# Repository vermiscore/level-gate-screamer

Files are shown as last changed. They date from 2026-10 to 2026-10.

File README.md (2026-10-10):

# level-gate-screamer
Tube Screamer-style overdrive with a level gate: attenuates below threshold, boosts above

> [!WARNING]
> **v1: J2/J3 footprints are rotated 180°.**
> Fix with jumpers on the bottom side:
> - J2: 1–6, 2–5
> - J3: 1–6, 4–2
>
> Next revision: rotate J2/J3 so the big protrusion faces the board edge.
>
> **Output level:** up to ~9 Vpp (rail-to-rail op-amps on 9 V).
> Check the input range of the next device before connecting.
> Tested OK with a Neural DSP Nano Cortex.

## Files
- `kicad_files/` — KiCad project
- `fabrication/` — Gerber, BOM, CPL for JLCPCB
- `hand_soldered_parts/` — parts not assembled by JLCPCB
- `simulation/` — ngspice netlist

## Images

### Finished PCB
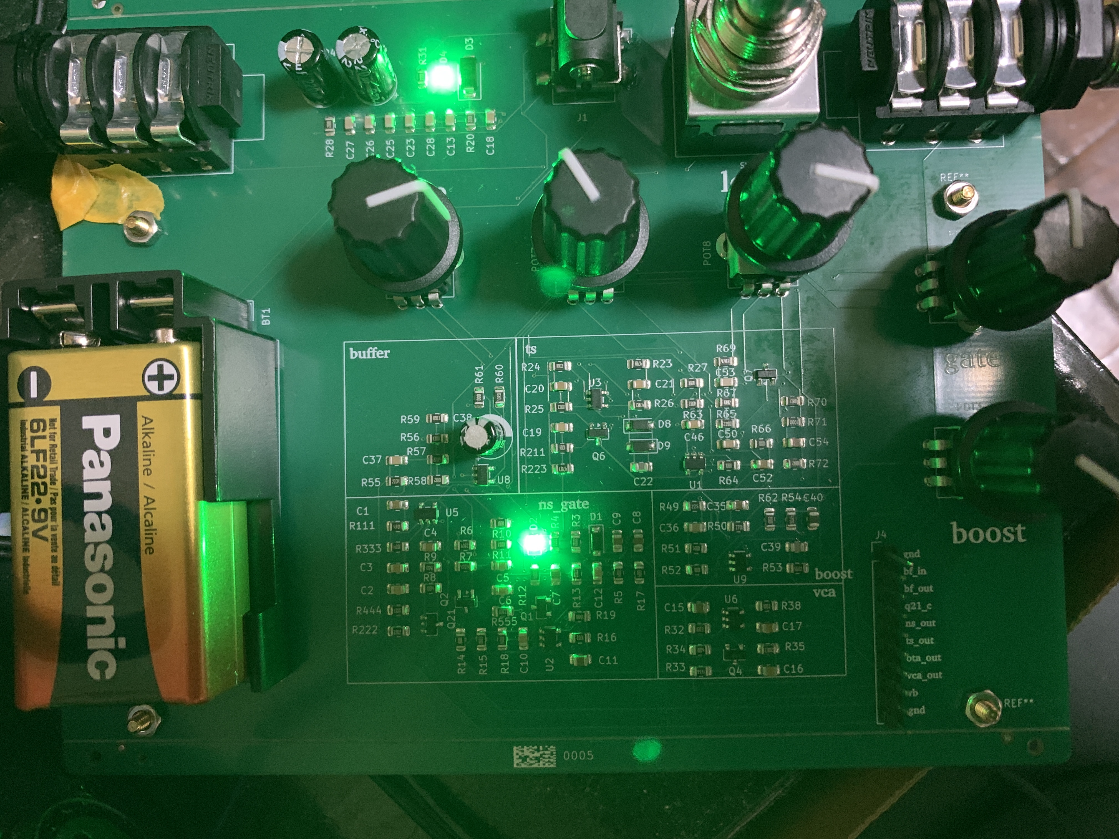
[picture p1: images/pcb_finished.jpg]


### PCB just arrived
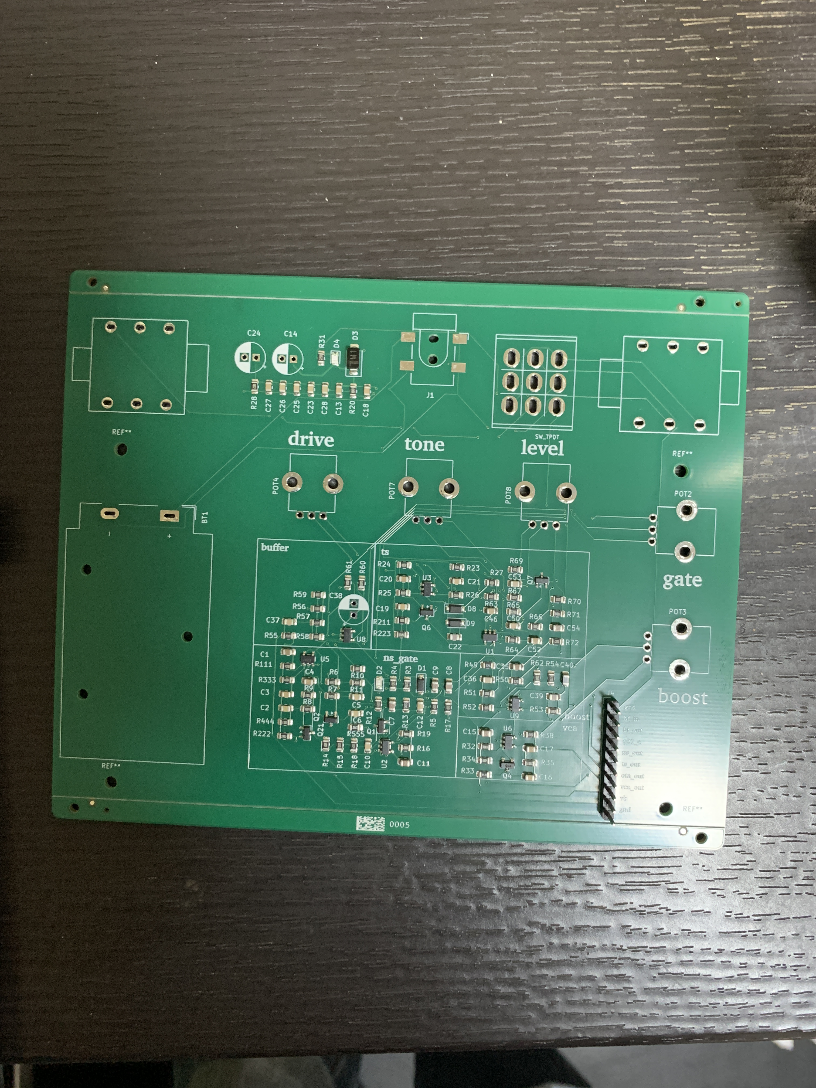
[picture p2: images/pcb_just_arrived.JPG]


### PCB layout (KiCad)
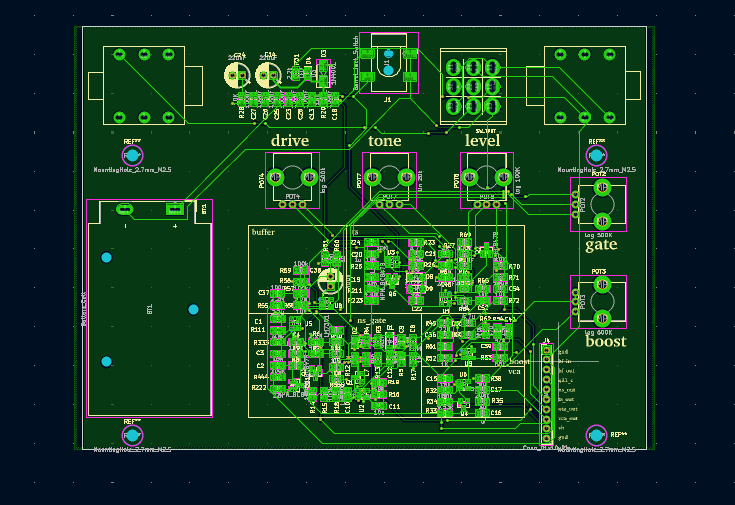
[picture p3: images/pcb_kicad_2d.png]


### Schematic
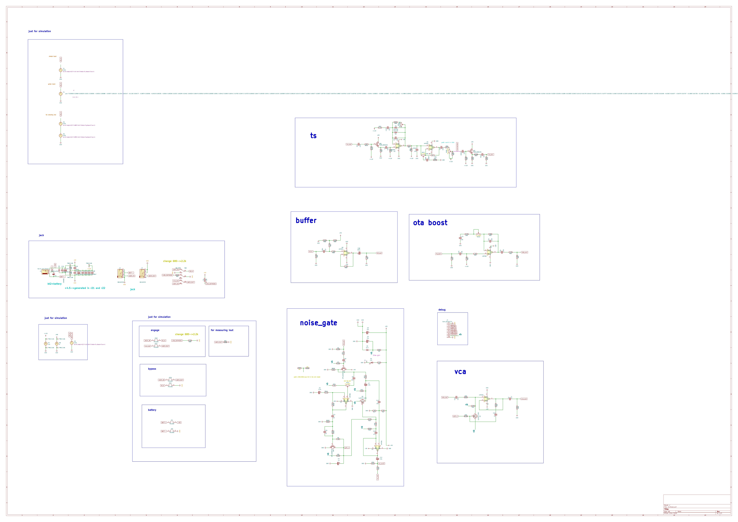
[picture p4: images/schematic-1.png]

Labeled as "OTA boost", but this isn't an OTA.
### Level gate concept
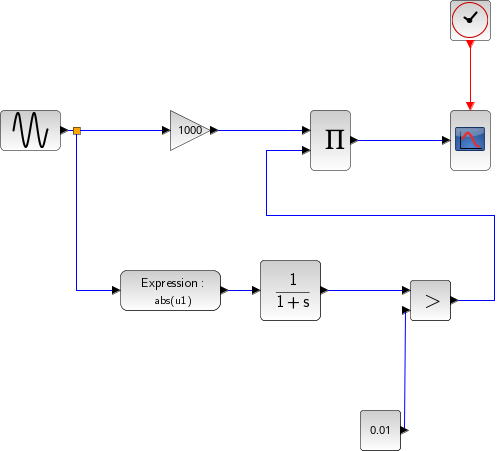
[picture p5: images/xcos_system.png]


### Simulation: input above threshold (amplified)


### Simulation: input below threshold (attenuated)


## Impressions
- Sounds great
- Easy to play
- The gate works as intended

## References
- [UC3Music/IceScreamer](https://github.com/UC3Music/IceScreamer) — base Tube Screamer design and footprints
- [ElectroSmash Archive: Tube Screamer Analysis](https://electrosmash.mas-effects.com/tube-screamer-analysis)
- [ElectroSmash Archive: MXR MicroAmp Analysis](https://electrosmash.mas-effects.com/mxr-microamp) — boost stage
- [PCB Guitar Mania: No-Noise Gate building docs (PDF)](https://pcbguitarmania.com/wp-content/uploads/2018/07/No-Noise-Gate-1.2v-Building-Docs.pdf) — noise gate
- [Elliott Sound Products: VCA Techniques Investigated](https://sound-au.com/articles/vca-techniques.html) — JFET VCA (Figure B)
- Boss NS-2 — gate idea: detect on the dry signal, mute after the gain stage

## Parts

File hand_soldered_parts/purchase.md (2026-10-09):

# Hand-soldered parts (purchase list)

| Ref | Part | Qty | Shop |
|---|---|---|---|
| J1 | Cliff FC681465S (DC jack, SMT) | 1 | [DigiKey](https://www.digikey.com/en/products/detail/cliff-electronic-components-ltd/FC681465S/16181279) |
| J2, J3 | Neutrik NMJ6HFD2 | 2 | [DigiKey](https://www.digikey.com/en/products/detail/neutrik-americas-inc/NMJ6HFD2/29427251) |
| BT1 | MPD BA9VPC (9V battery holder) | 1 | [DigiKey](https://www.digikey.com/en/products/detail/mpd-memory-protection-devices/BA9VPC/2439228) |
| SW1 | Alpha SF17010F-0302-21R-L (3PDT) | 1 | [stompboxparts](https://stompboxparts.com/footswitches/3pdt-footswitch-pcb-pin-alpha/) |
| POT2, POT3, POT4 | Bourns PTV09A-4020F-A504 (500k log) | 3 | [DigiKey](https://www.digikey.jp/en/products/detail/bourns-inc/PTV09A-4020F-A504/3781122) |
| POT7 | Bourns PTV09A-4020F-B203 (20k lin) | 1 | [DigiKey](https://www.digikey.jp/en/products/detail/bourns-inc/PTV09A-4020F-B203/3781126) |
| POT8 | Bourns PTV09A-4020F-A104 (100k log) | 1 | DigiKey |
| - | Knob 16mm x 18mm, D-shaft | 5 | [Amazon](https://www.amazon.com/uxcell-Potentiometer-Control-Electric-Acrylic/dp/B07T2VPRJX) |

## Pot assignment
| Ref | Value | Taper | Label |
|---|---|---|---|
| POT2 | 500k | log (A) | gate |
| POT3 | 500k | log (A) | boost |
| POT4 | 500k | log (A) | drive |
| POT7 | 20k | lin (B) | tone |
| POT8 | 100k | log (A) | level |

Note: v1 used PTV09A-4030F-A104 (30mm shaft) for POT8 by mistake.
4020F (20mm shaft) matches the other pots.

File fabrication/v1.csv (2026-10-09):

Reference | Qty | Value | DNP | Exclude from BOM | Exclude from Board | Footprint | Datasheet | LCSC Part
C1 | 1 | 2.2u |  |  |  | IceScreamer:C_0805_2012Metric_Pad1.15x1.40mm_HandSolder | ~
C2,C5,C6,C12 | 4 | 10n |  |  |  | IceScreamer:C_0805_2012Metric_Pad1.15x1.40mm_HandSolder
C3,C10 | 2 | 47n |  |  |  | IceScreamer:C_0805_2012Metric_Pad1.15x1.40mm_HandSolder
C4,C16,C17,C20 | 4 | 1u |  |  |  | IceScreamer:C_0805_2012Metric_Pad1.15x1.40mm_HandSolder | ~
C7,C8,C9,C11,C15 | 5 | 10u |  |  |  | IceScreamer:C_0805_2012Metric_Pad1.15x1.40mm_HandSolder | ~
C13,C18,C23,C25,C26,C27,C28,C53 | 8 | 100nF |  |  |  | IceScreamer:C_0805_2012Metric_Pad1.15x1.40mm_HandSolder
C19 | 1 | 22n |  |  |  | IceScreamer:C_0805_2012Metric_Pad1.15x1.40mm_HandSolder
C21 | 1 | 47nF |  |  |  | IceScreamer:C_0805_2012Metric_Pad1.15x1.40mm_HandSolder
C22,C39 | 2 | 47p |  |  |  | IceScreamer:C_0805_2012Metric_Pad1.15x1.40mm_HandSolder
C35 | 1 | 4.7u |  |  |  | IceScreamer:C_0805_2012Metric_Pad1.15x1.40mm_HandSolder
C36 | 1 | 0.1u |  |  |  | IceScreamer:C_0805_2012Metric_Pad1.15x1.40mm_HandSolder
C37 | 1 | 100n |  |  |  | IceScreamer:C_0805_2012Metric_Pad1.15x1.40mm_HandSolder
C40 | 1 | 15u |  |  |  | IceScreamer:C_0805_2012Metric_Pad1.15x1.40mm_HandSolder |  | C361175
C46,C50 | 2 | 220nF |  |  |  | IceScreamer:C_0805_2012Metric_Pad1.15x1.40mm_HandSolder
C52 | 1 | 1uF |  |  |  | IceScreamer:C_0805_2012Metric_Pad1.15x1.40mm_HandSolder
C54 | 1 | 10uF |  |  |  | IceScreamer:C_0805_2012Metric_Pad1.15x1.40mm_HandSolder
D1 | 1 | 5.1v |  |  |  | Diode_SMD:D_SOD-123 | ~ | C89693
D2,D4 | 2 | LED |  |  |  | LED_SMD:LED_0805_2012Metric | ~ | C2297
D3 | 1 | 1N4001 |  |  |  | Diode_SMD:D_SMA |  | C727079
D8,D9 | 2 | 1N4148 |  |  |  | Diode_SMD:D_SOD-123 |  | C81598
J4 | 1 | Conn_01x10_Pin |  |  |  | Connector_PinHeader_2.54mm:PinHeader_1x10_P2.54mm_Vertical | ~
Q1,Q4 | 2 | Q_NJFET_GDS |  |  |  | easyeda2kicad:SOT-23-3_L2.9-W1.3-P1.90-LS2.4-BR | https://www.lcsc.com/datasheet/C2830807.pdf | C2830807
Q2,Q6,Q7,Q21 | 4 | NPN_BC847B |  |  |  | Package_TO_SOT_SMD:SOT-23 | http://www.infineon.com/dgdl/Infineon-BC847SERIES_BC848SERIES_BC849SERIES_BC850SERIES-DS-v01_01-en.pdf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 | C5952857
R3,R13,R222,R555 | 4 | 22k |  |  |  | IceScreamer:R_0805_2012Metric_Pad1.15x1.40mm_HandSolder
R4 | 1 | 3.3k |  |  |  | IceScreamer:R_0805_2012Metric_Pad1.15x1.40mm_HandSolder
R5,R8,R12,R17,R18,R34,R333 | 7 | 1M |  |  |  | IceScreamer:R_0805_2012Metric_Pad1.15x1.40mm_HandSolder
R6,R55,R57 | 3 | 2.2M |  |  |  | IceScreamer:R_0805_2012Metric_Pad1.15x1.40mm_HandSolder
R7 | 1 | 470k |  |  |  | IceScreamer:R_0805_2012Metric_Pad1.15x1.40mm_HandSolder
R9 | 1 | 150k |  |  |  | IceScreamer:R_0805_2012Metric_Pad1.15x1.40mm_HandSolder
R10 | 1 | 1k |  |  |  | IceScreamer:R_0805_2012Metric_Pad1.15x1.40mm_HandSolder
R11,R16,R38,R58,R62 | 5 | 10k |  |  |  | IceScreamer:R_0805_2012Metric_Pad1.15x1.40mm_HandSolder
R14 | 1 | 1.8k |  |  |  | IceScreamer:R_0805_2012Metric_Pad1.15x1.40mm_HandSolder
R15,R32,R56,R59,R444 | 5 | 100k |  |  |  | IceScreamer:R_0805_2012Metric_Pad1.15x1.40mm_HandSolder
R19,R61 | 2 | 100 |  |  |  | IceScreamer:R_0805_2012Metric_Pad1.15x1.40mm_HandSolder
R20,R24,R25,R28,R63,R67,R70,R72 | 8 | 10K |  |  |  | IceScreamer:R_0805_2012Metric_Pad1.15x1.40mm_HandSolder
R23,R111 | 2 | 4.7k |  |  |  | IceScreamer:R_0805_2012Metric_Pad1.15x1.40mm_HandSolder
R26 | 1 | 47k |  |  |  | IceScreamer:R_0805_2012Metric_Pad1.15x1.40mm_HandSolder
R27,R52,R64,R66,R211 | 5 | 1K |  |  |  | IceScreamer:R_0805_2012Metric_Pad1.15x1.40mm_HandSolder
R31 | 1 | 2.2k |  |  |  | IceScreamer:R_0805_2012Metric_Pad1.15x1.40mm_HandSolder
R33 | 1 | 9.53k |  |  |  | IceScreamer:R_0805_2012Metric_Pad1.15x1.40mm_HandSolder
R35 | 1 | 200k |  |  |  | IceScreamer:R_0805_2012Metric_Pad1.15x1.40mm_HandSolder
R49 | 1 | 22M |  |  |  | IceScreamer:R_0805_2012Metric_Pad1.15x1.40mm_HandSolder
R50 | 1 | 2.7k |  |  |  | IceScreamer:R_0805_2012Metric_Pad1.15x1.40mm_HandSolder
R51 | 1 | 10M |  |  |  | IceScreamer:R_0805_2012Metric_Pad1.15x1.40mm_HandSolder
R53 | 1 | 56k |  |  |  | IceScreamer:R_0805_2012Metric_Pad1.15x1.40mm_HandSolder
R54 | 1 | 470 |  |  |  | IceScreamer:R_0805_2012Metric_Pad1.15x1.40mm_HandSolder
R60 | 1 | 10 |  |  |  | IceScreamer:R_0805_2012Metric_Pad1.15x1.40mm_HandSolder
R65 | 1 | 220R |  |  |  | IceScreamer:R_0805_2012Metric_Pad1.15x1.40mm_HandSolder
R69,R223 | 2 | 470K |  |  |  | IceScreamer:R_0805_2012Metric_Pad1.15x1.40mm_HandSolder
R71 | 1 | 100R |  |  |  | IceScreamer:R_0805_2012Metric_Pad1.15x1.40mm_HandSolder
U1,U2,U3,U5,U6,U8,U9 | 7 | LM7301 |  |  |  | easyeda2kicad:SOT-23-5_L2.9-W1.6-P0.95-LS2.8-BL | https://lcsc.com/product-detail/General-Purpose-Amplifiers_Texas-Instruments-Texas-Instruments-LM7301IM5X-NOPB_C468181.html | C468181
BT1 | 1 | Battery_Cell |  | Excluded from BOM |  | Battery:BatteryHolder_MPD_BA9VPC_1xPP3
C14,C24 | 2 | 220uF |  | Excluded from BOM |  | IceScreamer:CP_Radial_D6.3mm_P2.50mm
C38 | 1 | 100u |  | Excluded from BOM |  | IceScreamer:CP_Radial_D6.3mm_P2.50mm | ~
J1 | 1 | Barrel_Jack_Switch |  | Excluded from BOM |  | Connector_BarrelJack:BarrelJack_CLIFF_FC681465S_SMT_Horizontal | ~
J2,J3 | 2 | NMJ6HFD2 |  | Excluded from BOM |  | IceScreamer:IceJACK
JP1,JP3,JP20,JP21,JP30,JP31 | 6 | PSEUDO |  | Excluded from BOM | Excluded from board | Jumper:SolderJumper-2_P1.3mm_Open_RoundedPad1.0x1.5mm
POT2,POT3 | 2 | log 500K |  | Excluded from BOM |  | Potentiometer_THT:Potentiometer_Bourns_PTV09A-1_Single_Vertical
POT4 | 1 | log 500k |  | Excluded from BOM |  | Potentiometer_THT:Potentiometer_Bourns_PTV09A-1_Single_Vertical
POT7 | 1 | lin 20k |  | Excluded from BOM |  | Potentiometer_THT:Potentiometer_Bourns_PTV09A-1_Single_Vertical
POT8 | 1 | log 100K |  | Excluded from BOM |  | Potentiometer_THT:Potentiometer_Bourns_PTV09A-1_Single_Vertical
R1 | 1 | 50k |  | Excluded from BOM | Excluded from board | IceScreamer:R_0805_2012Metric_Pad1.15x1.40mm_HandSolder
R2 | 1 | 450k |  | Excluded from BOM | Excluded from board | IceScreamer:R_0805_2012Metric_Pad1.15x1.40mm_HandSolder
R21 | 1 | 100k |  | Excluded from BOM | Excluded from board | IceScreamer:R_0805_2012Metric_Pad1.15x1.40mm_HandSolder
R29 | 1 | 2.2k |  | Excluded from BOM | Excluded from board | IceScreamer:R_0805_2012Metric_Pad1.15x1.40mm_HandSolder
SW1 | 1 | SW_TPDT |  | Excluded from BOM |  | IceScreamer:IceStomp_Switch_3PDT
V1,V5,V6,V9 | 4 | VSIN |  | Excluded from BOM | Excluded from board |  | https://ngspice.sourceforge.io/docs/ngspice-html-manual/manual.xhtml#sec_Independent_Sources_for
V4 | 1 | pwl="0.00000 0.0068 0.00029 0.0221 0.00059 -0.0035 0.00088 -0.0597 0.00118 -0.1041 0.00147 -0.1126 0.00177 -0.0879 0.00206 -0.0420 0.00235 -0.0014 0.00265 0.0231 0.00294 0.0461 0.00324 0.0649 0.00353 0.0759 0.00383 0.0811 0.00412 0.0819 0.00441 0.0792 0.00471 0.0733 0.00500 0.0647 0.00530 0.0541 0.00559 0.0434 0.00589 0.0319 0.00618 0.0149 0.00647 0.0081 0.00677 0.0287 0.00706 0.0623 0.00736 0.0892 0.00765 0.1027 0.00795 0.0799 0.00824 -0.0041 0.00853 -0.0989 0.00883 -0.1670 0.00912 -0.1988 0.00942 -0.1879 0.00971 -0.1476 0.01001 -0.1097 0.01030 -0.0834 0.01059 -0.0550 0.01089 -0.0285 0.01118 -0.0078 0.01148 0.0087 0.01177 0.0216 0.01207 0.0303 0.01236 0.0349 0.01265 0.0361 0.01295 0.0345 0.01324 0.0320 0.01354 0.0284 0.01383 0.0182 0.01413 0.0179 0.01442 0.0423 0.01471 0.0777 0.01501 0.1063 0.01530 0.1220 0.01560 0.1009 0.01589 0.0207 0.01619 -0.0703 0.01648 -0.1363 0.01677 -0.1679 0.01707 -0.1580 0.01736 -0.1183 0.01766 -0.0818 0.01795 -0.0561 0.01825 -0.0290 0.01854 -0.0036 0.01883 0.0163 0.01913 0.0320 0.01942 0.0444 0.01972 0.0528 0.02001 0.0572 0.02031 0.0580 0.02060 0.0559 0.02089 0.0525 0.02119 0.0473 0.02148 0.0342 0.02178 0.0320 0.02207 0.0544 0.02237 0.0874 0.02266 0.1152 0.02295 0.1314 0.02325 0.1093 0.02354 0.0316 0.02384 -0.0594 0.02413 -0.1292 0.02443 -0.1648 0.02472 -0.1585 0.02501 -0.1209 0.02531 -0.0867 0.02560 -0.0620 0.02590 -0.0356 0.02619 -0.0111 0.02649 0.0075 0.02678 0.0221 0.02707 0.0330 0.02737 0.0400 0.02766 0.0442 0.02796 0.0457 0.02825 0.0425 0.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 |  | Excluded from BOM | Excluded from board |  | https://ngspice.sourceforge.io/docs/ngspice-html-manual/manual.xhtml#sec_Independent_Sources_for
V7 | 1 | 4.5 |  | Excluded from BOM | Excluded from board |  | https://ngspice.sourceforge.io/docs/ngspice-html-manual/manual.xhtml#sec_Independent_Sources_for
V8 | 1 | 9 |  | Excluded from BOM | Excluded from board |  | https://ngspice.sourceforge.io/docs/ngspice-html-manual/manual.xhtml#sec_Independent_Sources_for

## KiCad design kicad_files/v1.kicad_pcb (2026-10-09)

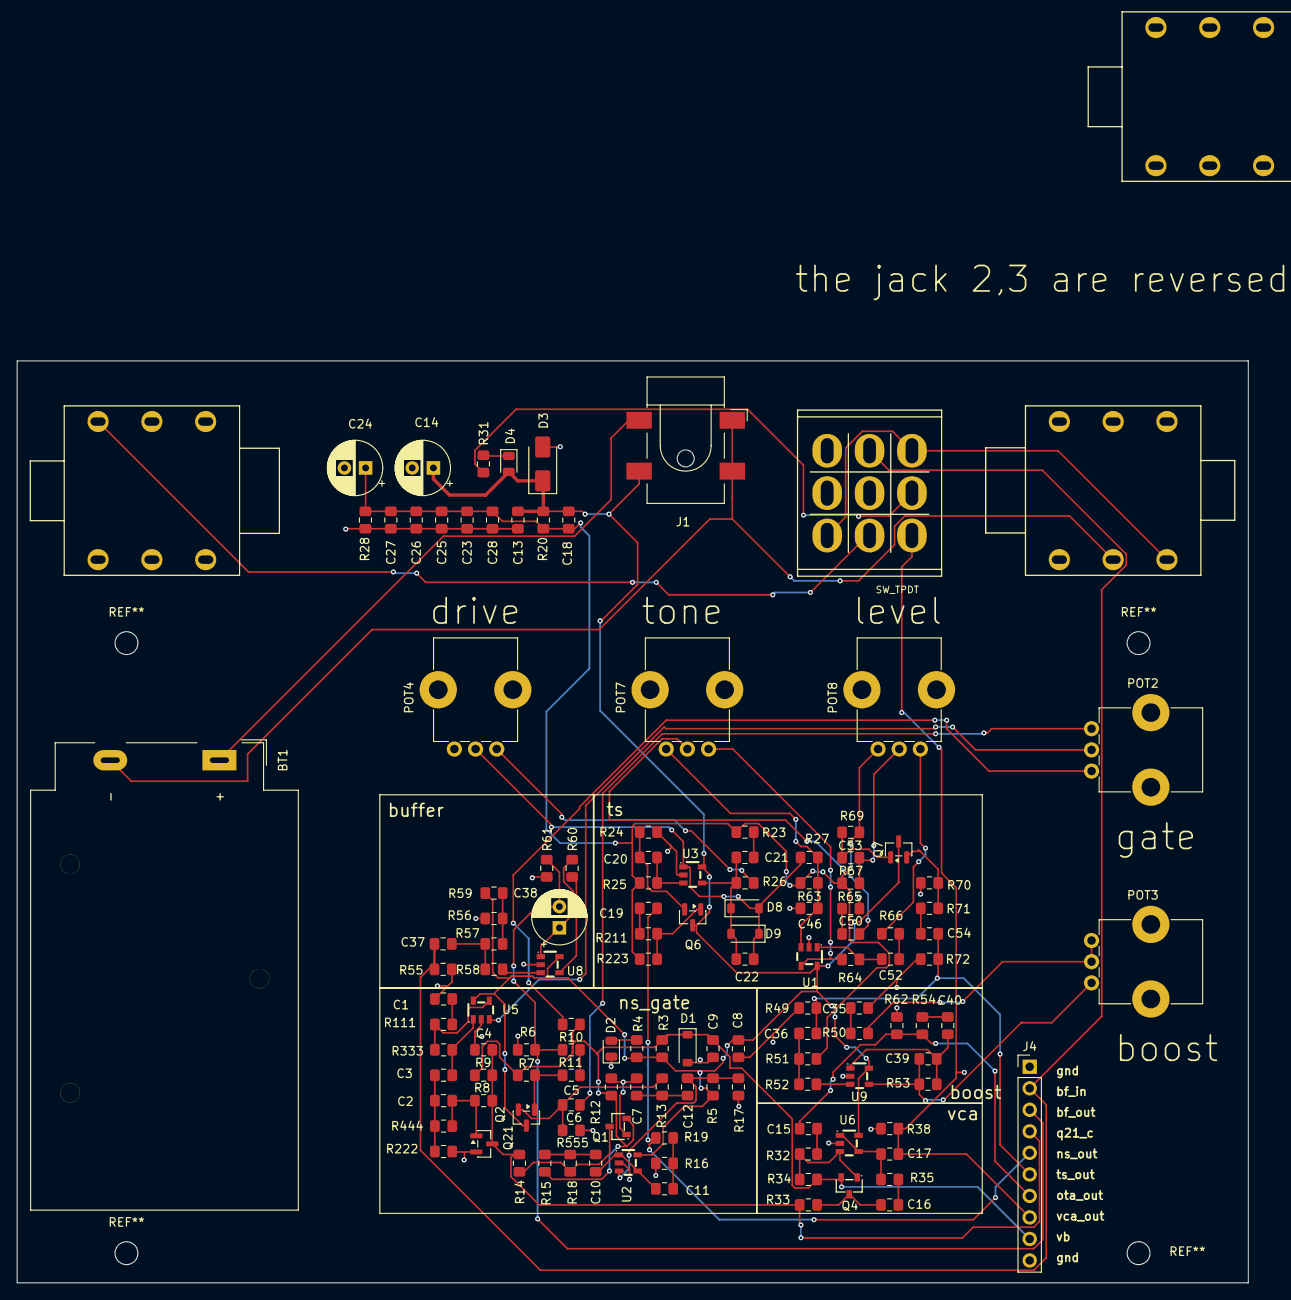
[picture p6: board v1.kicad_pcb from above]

Board: 2 copper layers, 145.3 x 108.8 mm, 130 parts (0 on the bottom side), 72 nets.

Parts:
BT1: Battery_Cell; BatteryHolder_MPD_BA9VPC_1xPP3
C1: 2.2u; C_0805_2012Metric_Pad1.15x1.40mm_HandSolder
C2, C5, C6, C12: 10n; C_0805_2012Metric_Pad1.15x1.40mm_HandSolder
C3, C10: 47n; C_0805_2012Metric_Pad1.15x1.40mm_HandSolder
C4, C16, C17, C20: 1u; C_0805_2012Metric_Pad1.15x1.40mm_HandSolder
C7, C8, C9, C11, C15: 10u; C_0805_2012Metric_Pad1.15x1.40mm_HandSolder
C13, C18, C23, C25, C26, C27, C28, C53: 100nF; C_0805_2012Metric_Pad1.15x1.40mm_HandSolder
C14, C24: 220uF; CP_Radial_D6.3mm_P2.50mm
C19: 22n; C_0805_2012Metric_Pad1.15x1.40mm_HandSolder
C21: 47nF; C_0805_2012Metric_Pad1.15x1.40mm_HandSolder
C22, C39: 47p; C_0805_2012Metric_Pad1.15x1.40mm_HandSolder
C35: 4.7u; C_0805_2012Metric_Pad1.15x1.40mm_HandSolder
C36: 0.1u; C_0805_2012Metric_Pad1.15x1.40mm_HandSolder
C37: 100n; C_0805_2012Metric_Pad1.15x1.40mm_HandSolder
C38: 100u; CP_Radial_D6.3mm_P2.50mm
C40: 15u; C_0805_2012Metric_Pad1.15x1.40mm_HandSolder
C46, C50: 220nF; C_0805_2012Metric_Pad1.15x1.40mm_HandSolder
C52: 1uF; C_0805_2012Metric_Pad1.15x1.40mm_HandSolder
C54: 10uF; C_0805_2012Metric_Pad1.15x1.40mm_HandSolder
D1: 5.1v; D_SOD-123
D2, D4: LED; LED_0805_2012Metric
D3: 1N4001; D_SMA
D8, D9: 1N4148; D_SOD-123
J1: Barrel_Jack_Switch; BarrelJack_CLIFF_FC681465S_SMT_Horizontal
J2, J2#2, J3: NMJ6HFD2; IceJACK
J4: Conn_01x10_Pin; PinHeader_1x10_P2.54mm_Vertical
POT2, POT3: log 500K; Potentiometer_Bourns_PTV09A-1_Single_Vertical
POT4: log 500k; Potentiometer_Bourns_PTV09A-1_Single_Vertical
POT7: lin 20k; Potentiometer_Bourns_PTV09A-1_Single_Vertical
POT8: log 100K; Potentiometer_Bourns_PTV09A-1_Single_Vertical
Q1, Q4: Q_NJFET_GDS; SOT-23-3_L2.9-W1.3-P1.90-LS2.4-BR
Q2, Q6, Q7, Q21: NPN_BC847B; SOT-23
R3, R13, R222, R555: 22k; R_0805_2012Metric_Pad1.15x1.40mm_HandSolder
R4: 3.3k; R_0805_2012Metric_Pad1.15x1.40mm_HandSolder
R5, R8, R12, R17, R18, R34, R333: 1M; R_0805_2012Metric_Pad1.15x1.40mm_HandSolder
R6, R55, R57: 2.2M; R_0805_2012Metric_Pad1.15x1.40mm_HandSolder
R7: 470k; R_0805_2012Metric_Pad1.15x1.40mm_HandSolder
R9: 150k; R_0805_2012Metric_Pad1.15x1.40mm_HandSolder
R10: 1k; R_0805_2012Metric_Pad1.15x1.40mm_HandSolder
R11, R16, R38, R58, R62: 10k; R_0805_2012Metric_Pad1.15x1.40mm_HandSolder
R14: 1.8k; R_0805_2012Metric_Pad1.15x1.40mm_HandSolder
R15, R32, R56, R59, R444: 100k; R_0805_2012Metric_Pad1.15x1.40mm_HandSolder
R19, R61: 100; R_0805_2012Metric_Pad1.15x1.40mm_HandSolder
R20, R24, R25, R28, R63, R67, R70, R72: 10K; R_0805_2012Metric_Pad1.15x1.40mm_HandSolder
R23, R111: 4.7k; R_0805_2012Metric_Pad1.15x1.40mm_HandSolder
R26: 47k; R_0805_2012Metric_Pad1.15x1.40mm_HandSolder
R27, R52, R64, R66, R211: 1K; R_0805_2012Metric_Pad1.15x1.40mm_HandSolder
R31: 2.2k; R_0805_2012Metric_Pad1.15x1.40mm_HandSolder
R33: 9.53k; R_0805_2012Metric_Pad1.15x1.40mm_HandSolder
R35: 200k; R_0805_2012Metric_Pad1.15x1.40mm_HandSolder
R49: 22M; R_0805_2012Metric_Pad1.15x1.40mm_HandSolder
R50: 2.7k; R_0805_2012Metric_Pad1.15x1.40mm_HandSolder
R51: 10M; R_0805_2012Metric_Pad1.15x1.40mm_HandSolder
R53: 56k; R_0805_2012Metric_Pad1.15x1.40mm_HandSolder
R54: 470; R_0805_2012Metric_Pad1.15x1.40mm_HandSolder
R60: 10; R_0805_2012Metric_Pad1.15x1.40mm_HandSolder
R65: 220R; R_0805_2012Metric_Pad1.15x1.40mm_HandSolder
R69, R223: 470K; R_0805_2012Metric_Pad1.15x1.40mm_HandSolder
R71: 100R; R_0805_2012Metric_Pad1.15x1.40mm_HandSolder
SW1: SW_TPDT; IceStomp_Switch_3PDT
U1, U2, U3, U5, U6, U8, U9: LM7301; SOT-23-5_L2.9-W1.6-P0.95-LS2.8-BL

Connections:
+4.5V: C18.2, C23.1, C24.1, C25.1, C26.1, C27.1, C28.1, POT8.3, R20.2, R23.1, R25.2, R28.1, R51.1, R63.1, R67.2, R69.2, R223.2
+9V: C8.1, C13.1, C14.1, C18.1, D3.1 (K), D4.2 (A), J1.2, Q2.3 (C), Q6.3 (C), Q7.3 (C), R3.2, R4.2, R5.2, R20.1, R59.2, U1.5 (VDD), U2.5 (VDD), U3.5 (VDD), U5.5 (VDD), U6.5 (VDD), U8.5 (VDD), U9.5 (VDD)
/vb: C9.1, D1.1 (K), J4.9, Q1.2 (S), Q4.2 (S), R3.1, R7.2, R9.2, R10.2, R12.2, R15.1, R34.1
BATT+: BT1.1 (+), J1.3
BATT-: BT1.2 (-), J1.1, J2#2.2
GND: C1.2, C4.2, C8.2, C9.2, C13.2, C14.2, C23.2, C24.2, C25.2, C26.2, C27.2, C28.2, C35.1, C46.1, D1.2 (A), D2.1 (K), D3.2 (A), J2#2.3, J2#2.4, J3.2, J3.3, J4.1, J4.10, Q21.2 (E), R6.2, R16.2, R17.1, R24.2, R28.2, R38.1, R49.1, R55.1, R56.1, R61.1, R62.1, R65.2, R70.2, R72.2, R222.2, R555.2, SW1.22, SW1.31, U1.2 (GND), U2.2 (GND), U3.2 (GND), U5.2 (GND), U6.2 (GND), U8.2 (GND), U9.2 (GND)
JACK_IN: J2#2.1, SW1.11, SW1.33
JACK_OUT: J3.1, SW1.23
LED_CATHODE: D4.1 (K), R31.1
unnamed: C1.1, R111.2
unnamed: C2.2, C3.1, R222.1, R444.2
unnamed: C5.2, R11.2
unnamed: C6.2, POT2.3
unnamed: C10.1, R15.2, R18.2
unnamed: C7.1, C12.1, R13.2
unnamed: C15.2, R32.2
unnamed: C16.1, R35.1
unnamed: C19.1, R211.2
unnamed: C21.2, R23.2
unnamed: C35.2, R50.1
unnamed: C36.1, R51.2, R52.1
unnamed: C37.1, R57.1, R58.1
unnamed: C40.1, R54.1
unnamed: C50.1, POT7.2
unnamed: C50.2, R65.1
unnamed: C52.1, R66.1
unnamed: C54.2, R71.1
unnamed: D2.2 (A), R4.1
unnamed: C22.1, D8.2 (A), D9.1 (K), POT4.2, R27.2, U3.1 (VOUT)
unnamed: C21.1, C22.2, D8.1 (K), D9.2 (A), R26.2, U3.4 (VIN-)
unnamed: POT2.1, R10.1
unnamed: POT3.2, POT3.3, R50.2
unnamed: POT4.1, R26.1
unnamed: POT8.1, R66.2
unnamed: C7.2, Q1.1 (D), R12.1
unnamed: Q1.3 (G), R14.2, R18.1
unnamed: C5.1, Q2.1 (B), R7.1
unnamed: C6.1, Q2.2 (E), R13.1, R555.1
unnamed: Q4.1 (D), R32.1, R34.2, U6.3 (VIN+)
unnamed: C16.2, Q4.3 (G), R33.1
unnamed: Q6.1 (B), R211.1, R223.1
unnamed: C20.2, Q6.2 (E), R24.1
unnamed: C53.1, Q7.1 (B), R69.1
unnamed: Q7.2 (E), R70.1, R71.2
unnamed: C2.1, Q21.1 (B), R8.2, R444.1
unnamed: R31.2, SW1.12
unnamed: R56.2, R57.2, R59.1
unnamed: C46.2, POT7.3, R27.1, R63.2, U1.3 (VIN+)
unnamed: POT7.1, R64.1, U1.4 (VIN-)
unnamed: C52.2, R64.2, U1.1 (VOUT)
unnamed: C12.2, R5.1, R17.2, U2.3 (VIN+)
unnamed: C10.2, C11.1, U2.1 (VOUT), U2.4 (VIN-)
unnamed: C20.1, R25.1, U3.3 (VIN+)
unnamed: POT2.2, U5.3 (VIN+)
unnamed: R111.1, R333.2, U5.4 (VIN-)
unnamed: C3.2, R333.1, U5.1 (VOUT)
unnamed: C17.2, R35.2, U6.1 (VOUT), U6.4 (VIN-)
unnamed: R58.2, U8.3 (VIN+)
unnamed: R60.1, U8.4 (VIN-)
unnamed: C38.1, R60.2, U8.1 (VOUT)
unnamed: R52.2, U9.3 (VIN+)
unnamed: C39.2, POT3.1, R53.1, U9.4 (VIN-)
unnamed: C39.1, C40.2, R53.2, U9.1 (VOUT)
TS_OUT: C36.2, C54.1, J4.6, R49.2, R72.1
bf_in: C37.2, J4.2, R55.2, SW1.21
bf_out: C38.2, J4.3, R6.1, R11.1, R61.2
connected: C53.2, POT8.2, R67.1
ns_out: C19.2, J4.5, R19.1
ns_out2: C11.2, R16.1, R19.2
ota_out: C15.1, J4.7, R54.2, R62.2
q21_c: C4.1, J4.4, Q21.3 (C), R8.1, R9.1, R14.1, R33.2
vca_out: C17.1, J4.8, R38.2, SW1.13

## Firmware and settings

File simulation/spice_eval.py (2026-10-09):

#!/usr/bin/env python3
"""
spice_eval.py -- interactive general-purpose evaluation tool for ngspice netlists.

Just run it with no arguments:

    python3 spice_eval.py

It will:
  1. let you pick a .cir netlist from the current folder,
  2. let you pick an evaluation to run,
  3. ask a few follow-up questions specific to that evaluation,
  4. run ngspice and print the result.

Handles a common KiCad export gotcha automatically: components left
unconnected on the schematic (e.g. a reference pot) get node names like
'unconnected-_POT1-Pad1_'. ngspice's operating-point solver can fail on
these (singular matrix), so this tool patches a 1G-ohm resistor to GND
onto each such node before simulating. This does not change circuit
behavior; it only gives the solver a DC path. The original file on disk
is never modified.

Requires ngspice on PATH.
"""
import argparse
import os
import re
import subprocess
import sys
import tempfile

NETLIST_EXTS = (".cir", ".sp", ".spice", ".net", ".ckt")


# --------------------------------------------------------------------------
# Shared helpers
# --------------------------------------------------------------------------

def ask(prompt, default=None):
    try:
        s = input(prompt).strip()
    except EOFError:
        return default if default is not None else ""
    return s if s else (default if default is not None else "")


def choose_netlist():
    files = sorted(f for f in os.listdir(".")
                    if f.lower().endswith(NETLIST_EXTS) and os.path.isfile(f))
    if not files:
        typed = ask("No netlist files found here. Enter a path (or blank to quit): ")
        if not typed:
            sys.exit(0)
        return typed

    print("Netlists in this folder:")
    for i, f in enumerate(files, 1):
        print(f"  [{i}] {f}")
    while True:
        sel = ask(f"Pick a file [1-{len(files)}] (default 1): ", default="1")
        if sel.isdigit() and 1 <= int(sel) <= len(files):
            return files[int(sel) - 1]
        if os.path.exists(sel):
            return sel
        print("Invalid choice, try again.")


def parse_spice_value(s):
    """Convert SPICE-style value strings ('500k', '2.2u', '1Meg') to float."""
    s = s.strip()
    m = re.match(r'^([\d.]+)\s*([a-zA-Z]*)$', s)
    if not m:
        raise ValueError(f"Could not parse value: {s}")
    num, suffix = m.group(1), m.group(2).lower()
    mult = {'': 1, 'f': 1e-15, 'p': 1e-12, 'n': 1e-9, 'u': 1e-6,
             'm': 1e-3, 'k': 1e3, 'meg': 1e6, 'g': 1e9}
    factor = mult['meg'] if suffix.startswith('meg') else mult.get(suffix)
    if factor is None:
        raise ValueError(f"Unknown unit suffix: {suffix}")
    return float(num) * factor


def format_ohms(value):
    if value >= 1e6:
        return f"{value/1e6:.3f}Meg"
    if value >= 1e3:
        return f"{value/1e3:.3f}k"
    return f"{value:.1f}"


def patch_floating_nodes(text):
    """Add a 1G-ohm resistor to GND for every 'unconnected-...' node found.
    Fixes ngspice operating-point convergence on truly floating pins
    without altering circuit behavior or touching the original file."""
    nodes = sorted(set(re.findall(r'\bunconnected-\S+\b', text)))
    if not nodes:
        return text, []
    ghost_lines = [f"Rghost_patch{i} {node} GND 1G" for i, node in enumerate(nodes, 1)]
    if ".end" in text:
        idx = text.rstrip().rfind(".end")
        text = text[:idx] + "\n".join(ghost_lines) + "\n" + text[idx:]
    else:
        text = text + "\n" + "\n".join(ghost_lines) + "\n"
    return text, nodes


def replace_source_value(text, ref, value_str):
    """Replace the value field of a '<ref> <node1> <node2> <value> ...' line."""
    pattern = re.compile(rf'^({re.escape(ref)}\s+\S+\s+\S+\s+)(\S+)(.*)$', re.MULTILINE)
    new_text, n = pattern.subn(rf'\g<1>{value_str}\g<3>', text)
    return new_text, n


def zero_sin_amplitude(text, ref):
    """Set a SIN(...) source's amplitude to 0, to simulate 'no input signal'."""
    pattern = re.compile(
        rf'^({re.escape(ref)}\s+\S+\s+\S+\s+DC\s+\S+\s+SIN\(\s*\S+\s+)(\S+)(\s+.*\))',
        re.MULTILINE
    )
    new_text, n = pattern.subn(r'\g<1>0\g<3>', text)
    return new_text, n > 0


def build_tran_netlist(base_text, probes, tstep, tstop, out_path):
    """Insert a .tran + wrdata control block just before the final .end."""
    probe_str = " ".join(probes)
    control = f"""
.tran {tstep} {tstop}
.control
run
set wr_vecnames
set wr_singlescale
wrdata {out_path} {probe_str}
.endc
"""
    if ".end" in base_text:
        idx = base_text.rstrip().rfind(".end")
        return base_text[:idx] + control + "\n.end\n"
    return base_text + control + "\n.end\n"


def run_ngspice(cir_path):
    return subprocess.run(["ngspice", "-b", cir_path], capture_output=True, text=True)


def read_wrdata(path, probes):
    """Read a wrdata output file.

    ngspice's wrdata is inconsistent: for V(...) probes it writes a header
    line ('time v(x) v(y)'), but for i(...) (current) probes it writes NO
    header line at all -- the file starts directly with numeric data. To
    handle both cases reliably, this checks whether the first line looks
    numeric; if so, there is no header and columns are assigned positionally
    using `probes` (in the order they were passed to wrdata). If not, the
    first line is treated as the real header.

    Returns dict: lower-cased column name -> list[float], including 'time'.
    """
    with open(path) as f:
        first_line = f.readline()
    first_tokens = first_line.split()

    def looks_numeric(tok):
        try:
            float(tok)
            return True
        except ValueError:
            return False

    has_header = not (first_tokens and all(looks_numeric(t) for t in first_tokens))

    if has_header:
        header = [h.lower() for h in first_tokens]
        data_start_line = 1
    else:
        header = ["time"] + [p.lower() for p in probes]
        data_start_line = 0

    data = {h: [] for h in header}
    with open(path) as f:
        for i, line in enumerate(f):
            if i < data_start_line:
                continue
            parts = line.split()
            if len(parts) != len(header):
                continue
            try:
                vals = [float(p) for p in parts]
            except ValueError:
                continue
            for h, v in zip(header, vals):
                data[h].append(v)
    return data
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

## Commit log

2026-10-09 Add BOM, fabrication files and simulation
    [v1.csv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]
2026-10-09 Add purchase list for hand-soldered parts
2026-10-09 Add warning for J2/J3 footprint issue
    Added warning about J2/J3 footprint rotation and fix instructions.
2026-10-09 Update README with images and PCB details
    Added images and descriptions for finished PCB, arrival, layout, schematic, and simulations.
